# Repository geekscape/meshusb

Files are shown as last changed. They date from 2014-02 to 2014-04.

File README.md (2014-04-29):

meshusb
==========

MeshUSB hardware and documentation repository.
-----------
The MeshUSB board is a USB to serial companion to any XBee-style form factor radio board, such as the MeshThing variants.

Current version is v0.3.

Contents:
-----------
-Hardware - Source files for PCB production.
-Resources - Additional documentation.
-Reference - Mostly datasheets.

Warnings:
-----------
*Reverse polarity on either the battery or auxilliary battery inputs are a potential battery fire danger.
*Over-voltage on the auxilliary charging input has potential to damage the board.

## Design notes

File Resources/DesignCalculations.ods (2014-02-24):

These calculations are used to size the current limiting resistor, R30.
PMEG3005CT shottkey diode resides between the source and charging circuitry when using PV inputs. Circular dependencies exist, so figures are approximate only.
100ma=.3v forward diode | 500mA=.4v forward diode
0.3 | 0.4
 |  |  | Ohms
100ma |  |  | 1 | 2 | 4 | 5 | 8 | 10 | 12 | 15 | 16 | 22 | 25 | 33 | 47 | 68 | 100
max charge current at V: | 5 |  | 1.5 | 0.75 | 0.375 | 0.3 | 0.1875 | 0.15 | 0.125 | 0.1 | 0.09375 | 0.0681818182 | 0.06 | 0.0454545455 | 0.0319148936 | 0.0220588235 | 0.015
1C=120mA for 2450 button cell | 6 |  | 2.5 | 1.25 | 0.625 | 0.5 | 0.3125 | 0.25 | 0.2083333333 | 0.1666666667 | 0.15625 | 0.1136363636 | 0.1 | 0.0757575758 | 0.0531914894 | 0.0367647059 | 0.025
 | 9 |  | 5.5 | 2.75 | 1.375 | 1.1 | 0.6875 | 0.55 | 0.4583333333 | 0.3666666667 | 0.34375 | 0.25 | 0.22 | 0.1666666667 | 0.1170212766 | 0.0808823529 | 0.055
 | 12 |  | 8.5 | 4.25 | 2.125 | 1.7 | 1.0625 | 0.85 | 0.7083333333 | 0.5666666667 | 0.53125 | 0.3863636364 | 0.34 | 0.2575757576 | 0.1808510638 | 0.125 | 0.085
500ma
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

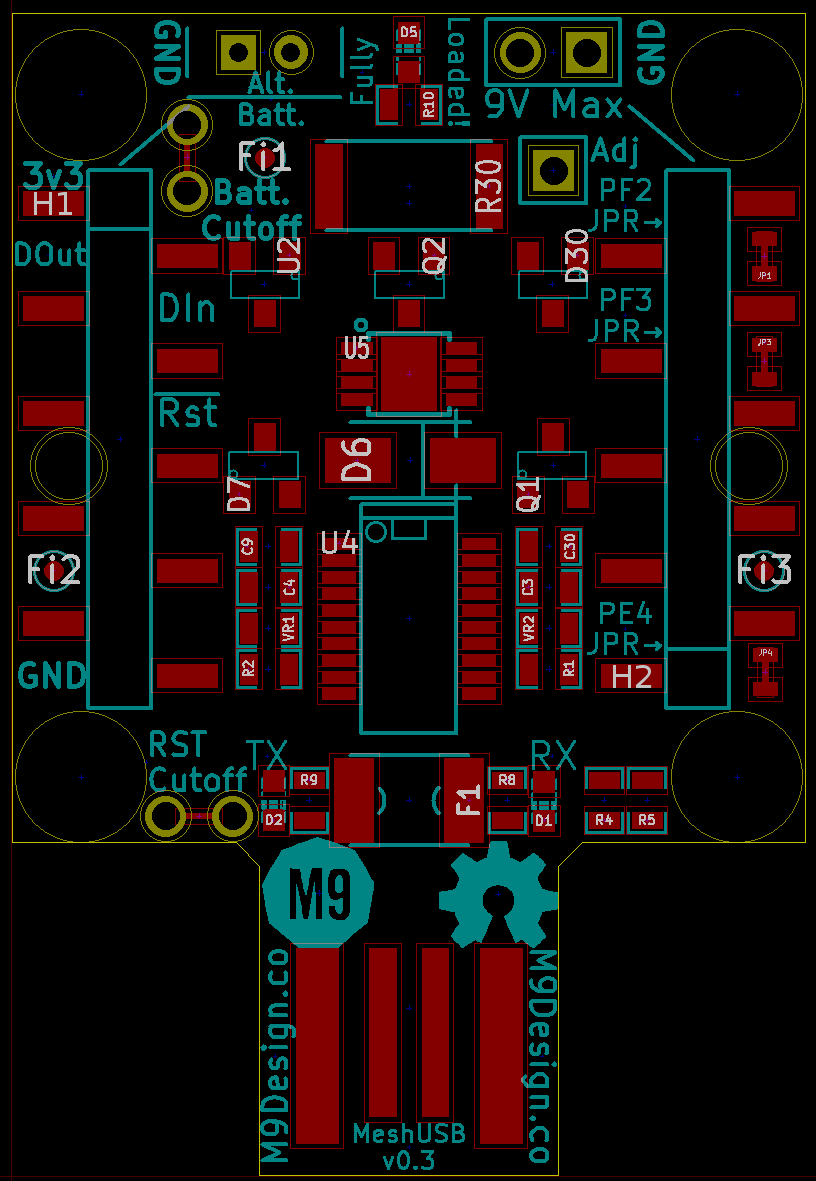
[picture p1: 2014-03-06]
Resources/MeshUSB-Render.png

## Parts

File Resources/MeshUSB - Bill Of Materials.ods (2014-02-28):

Part(s) | Reference | Value | Package | MFG. Part No. | Number | Fixed | Comment | Link | Digikey PartNo. | More Notes/Comments
SMD CAP | C3,C4,C9,C30 | 100n | SM0603 | C1608X7R1E104K080AA | 4 | YES | 25v rating | http://www.digikey.com/product-detail/en/C1608X7R1E104K080AA/445-1316-1-ND/567697 | 445-1316-1-ND
SMD LED | D1 | LED | SM0603 | LTST-C190KRKT | 1 | YES | 2v/red | http://www.digikey.com/product-detail/en/LTST-C190KRKT/160-1436-1-ND/386816 | 160-1436-1-ND | RX LED
SMD LED | D2 | LED | SM0603 | LTST-C190GKT | 1 | YES | 2v/green | http://www.digikey.com/product-detail/en/LTST-C190GKT/160-1183-1-ND/269255 | 160-1183-1-ND | TX LED
Dual Schottkey | D30 |  | SOT-23 | PMEG3005CT,215 | 1 | YES | 500mA per diode | http://www.digikey.com.au/product-detail/en/PMEG3005CT,215/568-6510-1-ND/2531797 | 568-6510-1-ND
SMD LED | D5 | LED | SM0603 | LTST-C193TBKT-5A | 1 | YES | 2.8v/blue/5ma/15mcd | http://www.digikey.com/product-detail/en/LTST-C193TBKT-5A/160-1827-1-ND/2355044 | 160-1827-1-ND | Charge Full LED
Zener Diode | D6 |  | DO-214AC | SMAZ5V6-13-F | 1 | YES | 5.6v Zener Breakdown | http://www.digikey.com.au/product-detail/en/SMAZ5V6-13-F/SMAZ5V6-FDICT-ND/755500 | SMAZ5V6-FDICT-ND
Diode | D7 |  | SOT-23 | DA3X101A0L | 1 | YES |  | http://www.digikey.com.au/product-detail/en/DA3X101A0L/DA3X101A0LCT-ND/2193677 | DA3X101A0LCT-ND
Fuse | F1 | Fuse | MF-MSMF050-2 | MF-MSMF050-2 | 1 | YES | 500ma | http://www.digikey.com.au/product-detail/en/MF-MSMF050-2/MF-MSMF050-2CT-ND/662842 | MF-MSMF050-2CT-ND
10 Pin 2mm Female Header | H1 | Header pins | 10x1 2mm spacing/ SMT | NPPN101BFLD-RC | 1 | YES | Pin 1 Right | http://www.digikey.com.au/product-search/en?vendor=0&keywords=NPPN101BFLD-RC | S5902-10-ND
10 Pin 2mm Female Header | H2 | Header pins | 10x1 2mm spacing/ SMT | NPPN101BFLC-RC | 1 | YES | Pin 1 Left | http://www.digikey.com.au/product-detail/en/NPPN101BFLC-RC/S5901-10-ND/810012 | S5901-10-ND | Pin one/ bottom to left. Surface Mount.
SMD Transistor | Q1 | PMOS | PG-SOT-23 | BSS83P H6327 | 1 | YES |  | http://www.digikey.com.au/product-detail/en/BSS83P%20H6327/BSS83P%20H6327CT-ND/3196656 | BSS83P H6327CT-ND
SMD Transistor | Q2 | PMOS | SOT-23 | FDN352AP | 1 | YES |  | http://www.digikey.com/product-detail/en/FDN352AP/FDN352APCT-ND/1849911 | FDN352APCT-ND
SMD R | R1,R2 | 22R | SM0603 | ERJ-3EKF22R0V | 2 | YES | .1W rating | http://www.digikey.com.au/product-detail/en/ERJ-3EKF22R0V/P22.0HCT-ND/1746745 | P22.0HCT-ND
SMD Power R | R30 | 16R | TE3521-Series_Resistor-6.3x3.2 | 352116RFT | 1 | YES | 2W rating | http://www.digikey.com/product-detail/en/352116RFT/A115989CT-ND/4280009 | A115989CT-ND
SMD R | R4 | 33k | SM0603 | ERJ-3GEYJ333V | 1 | YES | .1W rating | http://www.digikey.com.au/product-detail/en/ERJ-3GEYJ333V/P33KGCT-ND/134781 | P33KGCT-ND
SMD R | R5 | 20k | SM0603 | ERJ-3EKF2002V | 1 | YES | .1W rating | http://www.digikey.com.au/product-detail/en/ERJ-3EKF2002V/P20.0KHCT-ND/198237 | P20.0KHCT-ND
SMD R | R8,R9,R10 | 270R | SM0603 | ERJ-3GEYJ271V | 3 | YES | .1W rating | http://www.digikey.com.au/product-detail/en/ERJ-3GEYJ271V/P270GCT-ND/134766 | P270GCT-ND
3v3 Reg. | U2 |  | SOT-23 | AP7313-33SAG-7 | 1 | YES | 150mA | http://www.digikey.com.au/product-detail/en/AP7313-33SAG-7/AP7313-33SAG-7DICT-ND/2270840 | AP7313-33SAG-7DICT-ND
USB/Serial Comms IC | U4 | FT231X-SSOP | SSOP20 | FT231XS-U | 1 | YES |  | http://www.digikey.com.au/product-search/en/integrated-circuits-ics/interface-uarts-universal-asynchronous-receiver-transmitter/2556341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 | 768-1156-5-ND
Shunt Charge Regulator | U5 | LTC4070 | SSOP8-9 | LTC4070EMS8E#PBF | 1 | YES |  | http://www.digikey.com.au/product-detail/en/LTC4070EMS8E%23PBF/LTC4070EMS8E%23PBF-ND/2225710 | LTC4070EMS8E#PBF-ND
SMD VR | VR1,VR2 | Varistor | SM0603 | PGB1010603NRHF | 2 | YES |  | http://www.digikey.com.au/product-detail/en/PGB1010603NRHF/F4239CT-ND/3305589 | F4239CT-ND
NOT ASSEMBLED
Battery Holder | Li-Battery1 | 2450 Battery Holder | Retainer | BK-5033 | 1 | NO |  | http://www.digikey.com.au/product-detail/en/BK-5033/BK-5033-ND/2330512 | BK-5033-ND
Lithium Ion Rechargable Battery |  | LIR 3.6-3.7v | CR2450 |  | 1 | NO | 24.5(dia) x ~5.2(h)mm | Similar to: https://www.sparkfun.com/products/10319 |  | 120+ mAh

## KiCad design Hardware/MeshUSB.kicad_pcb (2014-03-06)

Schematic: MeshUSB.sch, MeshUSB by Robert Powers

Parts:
C3, C4, C9, C30: 100n
D1: RX_LED
D2: TX_LED
D5: LED
D6: ZENER
D7: DIODE-NC
D30: DUAL_SHOTTKEY_PACKAGE
F1: FUSE
Fi1, Fi2, Fi3: CONN_1
H1: XBeeLeftPins
H2: XBeeRightPins
JP1, JP3, JP4: JUMPER
JP2, JP5: CONN_TH_JMPR_DEFAULTCLOSED
Li-Battery1: BAT2
P1: USB_4
P2: PVCell
P30: JST_2
P31: CONN_1
Q1: MOS_P
Q2: MOS_P-INFINEON-BSS83P
R1, R2: 22R
R4: 33k
R5: 20k
R8, R9, R10: 270R
R30: 16R
U1: XBEE
U2: AP7313-3.3VREGULATOR
U4: FT231X-SSOP
U5: LTC4070
VR1, VR2: VR0603

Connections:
/BatConn+: JP5.2, Li-Battery1.1, P30.2 (PM)
/CC1: D30.3, R30.1
/Charge+: C30.1, D7.1 (K), JP5.1, Q1.2, Q2.2, R30.2, U5.2 (NTC), U5.8 (VCC)
/PV+: D30.2, P2.2 (PM)
/USBPwrIn: F1.1, P1.4 (GNDUSB)
BAT+: H1.1, U2.2
GND: C3.2, C4.2, C30.2, D6.1 (A), D7.3 (A), H1.10, Li-Battery1.2, P1.1 (VUSB), P2.1, P30.1, Q2.3, R10.1, U2.3, U4.6 (GND), U4.16 (GND), U5.5 (GND), U5.9 (PAD), VR1.2, VR2.2
unnamed: C9.1, JP2.1
unnamed: C9.2, U4.1 (~DTR)
unnamed: D1.1 (A), R8.2
unnamed: D1.2 (K), U4.17 (CBUS1)
unnamed: D2.1 (A), R9.2
unnamed: D2.2 (K), U4.10 (CBUS2)
unnamed: D5.2 (K), R10.2
unnamed: H1.2, U4.4 (RXD)
unnamed: H1.3, U4.20 (TXD)
unnamed: H1.5, JP2.2
unnamed: H2.1, JP4.1
unnamed: H2.7, JP3.1
unnamed: H2.8, JP1.1
unnamed: P1.2 (D-), R2.1, VR1.1
unnamed: P1.3 (D+), R1.1, VR2.1
unnamed: P31.1, U5.3 (ADJ)
unnamed: Q1.1, U5.6 (LBO)
unnamed: Q1.3, R4.2, U2.1
unnamed: Q2.1, U5.7 (DRV)
unnamed: R1.2, U4.12 (USBDM)
unnamed: R2.2, U4.11 (USBDP)
USB_VDD: C3.1, D6.2 (K), D30.1, F1.2, R8.1, R9.1, U4.15 (VCC)
VCCIO: C4.1, U4.3 (VCCIO), U4.13 (3v3OUT), U4.14 (~RESET)
_MT_PE4: JP4.2, R5.2
_MT_PF2: D5.1 (A), JP1.2, U5.4 (HBO)
_MT_PF3: JP3.2, R4.1, R5.1

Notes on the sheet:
MTTF Max Power can be set to allow for up to 500mA on the USB bus. 200mA is probably the max recommended - shouldn't need more under any circumstances. Default stays at 90mA for now.
ADJ -> Vcc= 4.2v Vout. ADJ -> NC=4.1v Vout. ADJ -> GND=4.0v Vout.
Charge Full Indicator... ...Active High! Seems this doesn't light when MT is inserted, think this should be fixed by changes to charging diodes.
R3 chosen to limit shunt current to 50mA. (4.5v-3.2v)/10=130mA max charge current. (4.5v-3.2v)^2/10=169mW PwrDiss (4.5v-4.1v)/40=mA max shunt current.
Conn_10s are for the smd headers in case I don't get around to incorporating them in a 20 pin xbee ff footprint.
PMOS1 does Low Battery cutoff.
Fw Drop Approx. 0.2V @ 100mA 0.3V @ 500mA
Still TODO for v0.3: Layout Fiducials. Jumpers for... what needs jumpers? Something must. Cutoff battery charging. Charge full indicator? Tx/Rx LEDs? USB vdd? Test points? Jump pads for 4070 AJD?
Charging max values charge I - 125mA=1C battery PwrDiss - 2W - depends on R30 shunt I - 50 mA
Exposed pins for charging... User must be careful! Do these as JST 2mm? Yes.
V.Div. Gives limited range. Get numbers from spreadsheet.
Approx. 6V max. without further current limiting. Diode forward current max. is 500mA.
This is for disabling soft reset ~DTR. Make as two .254mm THs connected by default.

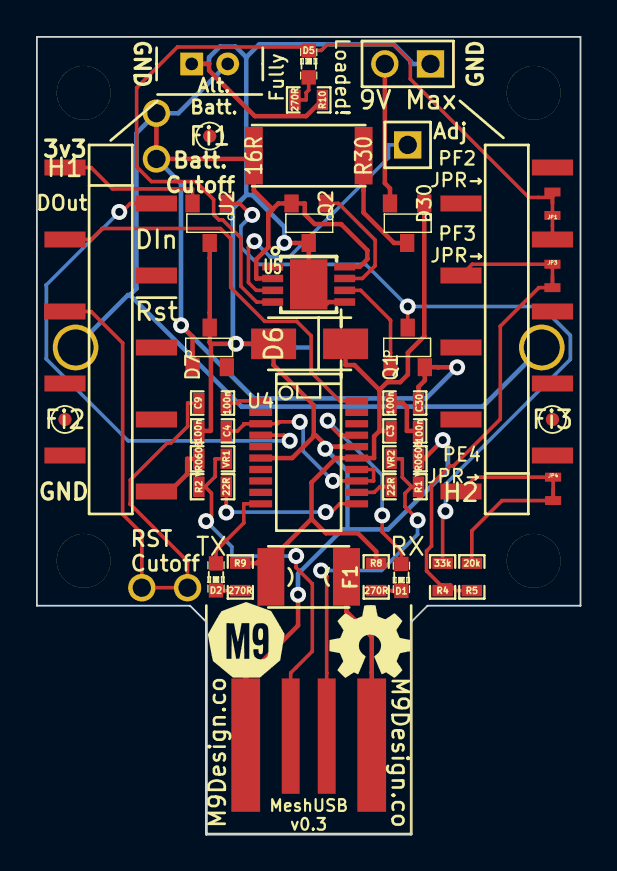
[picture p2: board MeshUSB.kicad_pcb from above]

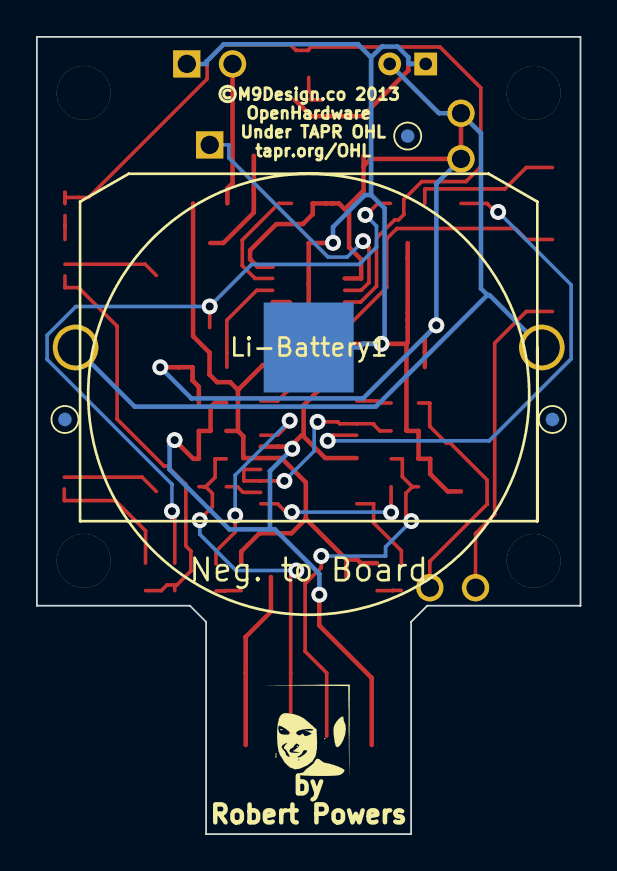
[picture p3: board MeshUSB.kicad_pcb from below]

Board: 2 copper layers, 30.2 x 44.3 mm, 49 parts (2 on the bottom side), 33 nets.

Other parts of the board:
1PIN1, 1PIN2, 1PIN3, 1PIN4: P***; _MUSB_3mmTH-1pin
G0, G1: LOGO
VAL: M9Logo-scaled

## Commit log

2013-10-05 Initial v0.1 final commit. Moving to v0.2 from here.
    [MeshUSB v0.1- Bill Of Materials.ods, MeshUSB.kicad_pcb, MeshUSB.preroute.kicad_pcb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]
2013-10-05 Getting moving on v0.2 :)
    [MeshUSB.kicad_pcb, MeshUSB.sch]
2013-10-09 More changes on list to v0.2.
    [MeshUSB.kicad_pcb, MeshUSB.sch]
2013-10-10 Moving away from LTC310X DCDC converters.
    [MeshUSB.sch]
2013-10-12 Almost everything on the TODO is done. Layout done.
    [MeshUSB.kicad_pcb, MeshUSB.sch]
2013-10-12 Additional trace to connect everything even in the event the battery holder is not in place.
    [MeshUSB.kicad_pcb]
2013-10-12 Fixed minor pad spacing error on FT231X non-standard SSOP20 package.
    [MeshUSB.kicad_pcb]
2013-10-12 It is probably best to not leave that pin unconnected.
    [MeshUSB.kicad_pcb]
2013-10-14 Added mounting holes, some SMT jumpers and a voltage divider. Extended board for mounts by 3.5mm.
    [MeshUSB.BOM.csv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]
2013-10-18 Removing Archive folder from git tracking.
    [MeshUSB v0.1- Bill Of Materials.ods, MeshUSBv0.1.BOM.csv, MeshUSBv0.1.dsn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]
2013-10-18 Cleaning up.
    [MeshUSB.preroute.kicad_pcb]
2013-10-22 Change all the things\!
    [MeshUSB-B_Cu.gbl, MeshUSB-B_Mask.gbs, MeshUSB-B_SilkS.gbo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]
2014-02-07 Mark for changes for v0.3.
    [MeshUSB.sch]
2014-02-19 Begin major modifications for post v0.2.
    [MeshUSB.kicad_pcb, MeshUSB.sch]
2014-02-20 Begin Layout. Still some schematic additions required.
    [MeshUSB.kicad_pcb, MeshUSB.sch]
2014-02-21 Further changes. Still looking for appropriate diode and PMOS packages.
    [MeshUSB.kicad_pcb, MeshUSB.sch]
2014-02-22 Schematic notes and library updates.
    [MeshUSB.kicad_pcb, MeshUSB.sch]
2014-02-23 .gitignore kicad-bak
2014-02-23 Higher current charging. Some datasheets.
    [MeshUSB.sch]
2014-02-24 Almost to layout. Charging slightly modified, confirming BOM.
    [MeshUSB.kicad_pcb, MeshUSB.sch]
2014-02-24 Layout positions nearly finalized.
    [MeshUSB.dsn, MeshUSB.kicad_pcb, MeshUSB.sch]
2014-02-24 Further placements, silks, refs. Next:Double check all pins and packages.
    [MeshUSB.kicad_pcb, MeshUSB.sch]
2014-02-24 Routed. In need of further review and a few more TODOs.
    [MeshUSB-B_Cu.gbl, MeshUSB-B_Mask.gbs, MeshUSB-B_Paste.gbp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]
2014-02-26 Layout & routing nearly final. Current carrying trace widths need to be embiggened.
    [MeshUSB.dsn, MeshUSB.kicad_pcb, MeshUSB.sch]
2014-02-26 Adding nets.
    [MeshUSB.kicad_pcb, MeshUSB.sch]
2014-02-26 Embiggining and reroute done. Double checks on pad-connect traces and via placements next.
    [MeshUSB.dsn, MeshUSB.kicad_pcb]
2014-02-27 Final touches, render, update some datasheets.
    [MeshUSB.BOM.csv, MeshUSB.kicad_pcb]
2014-02-28 V0.3 Production ready. This version sent for quote. TODO: Placements.
    [MeshUSB - Bill Of Materials.ods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]
2014-03-05 Positions and minor silk.
    [MeshUSB-B_Cu.gbl, MeshUSB-B_Mask.gbs, MeshUSB-B_Paste.gbp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]
2014-03-06 V0.3 production files.
    [MeshUSB-B_Cu.gbl, MeshUSB-B_Mask.gbs, MeshUSB-B_Paste.gbp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]
2014-05-02 Updated schematic notes and cleaned up library inconsistencies due to KiCAD version upgrade.
    [MeshUSB.sch]

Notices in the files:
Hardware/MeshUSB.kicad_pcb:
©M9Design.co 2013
